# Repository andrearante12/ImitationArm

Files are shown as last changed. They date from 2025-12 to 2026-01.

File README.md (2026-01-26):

# ImitationArm
This document presents Imitation Arm, a 6DOF robotic arm that learns skills by watching human demonstrations and mimicing movements. The end goal is to create a generalized system where a human can record a video of them picking up and placing an object and upload that to the arm. The arm will then decode the video and be able to copy the exact motion the human made completely autonomously.

## System Overview
A human can train the robot via a wearable device consisting of an ESP32 microcontroller and a MPU-6050 Acceleromter and Gyroscope sensor. Data is streamed over WiFi to the central RaspberryPi using MQTT messaging protocol. The RaspberryPI is responsible for callibration and smoothing the sensor data using various signal processing techniques.

The robotic system is controlled by six MG996R pulse-width modulation (PWM) servomotors, which are driven by a PCA9685 16-channel, 12-bit PWM servo controller interfaced via the I2C protocol. Low-level actuator control is handled by an Arduino Nano microcontroller.

High-level system control is implemented on a Raspberry Pi running the Robot Operating System (ROS), which is responsible for computationally intensive control tasks. The ROS2 workspace can be download here: https://github.com/andrearante12/ros2_ws. A custom inverse kinematic algorithm implemented via gradient descent and used to convert target coordinates (x, y, z) into the corresponding servo angles. MoveIt2 was then used to create a motion plan and verify that the path is valid via trajectory planning and collision detection. Control commands are transmitted from the Raspberry Pi to the Arduino Nano over a serial communication interface.

## Future Direction

The following features are in development:
- Vision assisted callibration for wearable controller using D435 Depth Camera
- Reinforcement Learning Based (Imitation Learning) algorithm for autonomous task execution

## System Requirements
- Developed on Ubuntu 24.04 (required for ROS2 Jazzy)
- ROS2 - Jazzy 
- Moveit2 - Harmonic

## Physical Build and Demonstration

Demo Video using breadboard based protoype of wearable controller.

https://github.com/user-attachments/assets/144eaac5-5938-4217-9122-2242566a99c5

Rough prototype of wearable controller

https://github.com/user-attachments/assets/a6dace8c-65ac-41af-8a9c-40d3fd4ca57d

<p align="center">
  
  
</p>

## Visualization and motion planning with rviz2

https://github.com/user-attachments/assets/5d312841-a5a9-4a7e-a08d-b234987b8f20

Succesful motion planning demonstration

https://github.com/user-attachments/assets/f96ab1f5-55c6-4020-97d4-8c81f729513d

## Components
PCA9685 Servo Driver: https://www.amazon.com/dp/B0CNVBWX2M?ref=ppx_yo2ov_dt_b_fed_asin_title

Aluminum Body (w/out servos): https://www.amazon.com/dp/B01LW0LUPT?ref=ppx_yo2ov_dt_b_fed_asin_title

MG996R Digital Servo Motor (x6): https://www.amazon.com/dp/B09LS7RB5J?ref=ppx_yo2ov_dt_b_fed_asin_title&th=1

External Power Source (5V 6A): https://www.amazon.com/dp/B01D8FM4N4?ref=ppx_yo2ov_dt_b_fed_asin_title&th=1 





## CAD Model with Solidworks

Note: the above mentioned aluminum body doesn't come with an official CAD model, so the below and attached Solidworks file are my own personal recreation.

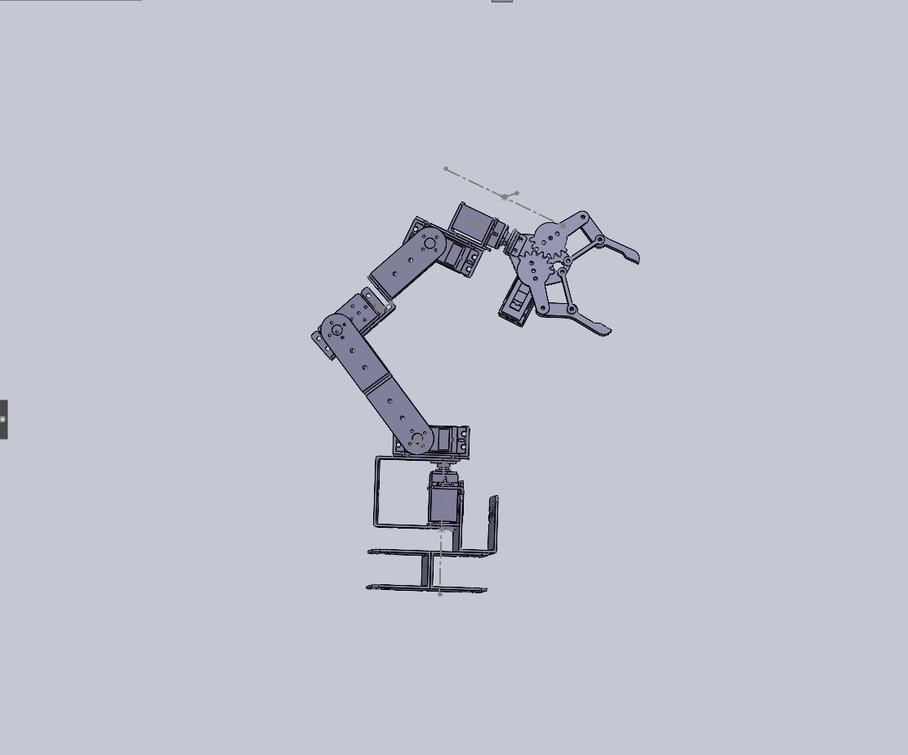
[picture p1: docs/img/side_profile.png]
Demo


### Steps to run

1. Install the ros2 package from this github repo: https://github.com/andrearante12/ros2_ws
```
cd ~/
git clone https://github.com/andrearante12/ros2_ws
```

2. Build the package (Full Rebuild)
```
cd ~/ros2_ws
rm -rf build install log
colcon build
source /opt/ros/jazzy/setup.bash
source install/setup.bash
```

Alternatively, a quick rebuild for select packages
```
cd ~/ros2_ws
colcon build --packages-select package_name
source install/setup.bash
```

3. Confirm that the distrubiton is working properly by launching the joint state manager with manual controls
```
ros2 launch robotic_arm robotic_arm.launch.py
```

## Starting the IMU Controller Pipeline

1. Run the motion planner with MoveIt and rviz2
```
ros2 launch robotic_arm_v3_config demo_with_controllers.launch.py
```

2. Run the IMU communication node
```
ros2 run mqtt_imu mqtt_imu_node
```

3. Run the IMU controller node

Run with the recommended callibration 
```
ros2 run esp32_controller esp32_controller --ros-args \
  -p callback_skip_rate:=5 \
  -p x_sensitivity:=3.0 \
  -p lock_y_axis:=true \
  -p default_y_position:=-1.2 \
  -p lock_wrist:=true \
  -p default_wrist_angle:=90 \
  -p default_z_position:=1.10

```

# ESP32 Controller - Quick Parameter Reference

| Parameter | Type | Default | Range/Options | Description |
|---|---|---|---|---|
| `callback_skip_rate` | int | 5 | 1-100 | Commands sent every N callbacks (higher = slower) |
| `x_sensitivity` | double | 1.5 | 0.1-10.0 | X-axis responsiveness (higher = more sensitive) |
| `y_sensitivity` | double | 2.0 | 0.1-10.0 | Y-axis responsiveness (higher = more sensitive) |
| `lock_x_axis` | bool | false | true/false | Lock X at current position |
| `lock_y_axis` | bool | false | true/false | Lock Y at default position |
| `lock_wrist` | bool | false | true/false | Lock wrist at default angle |
| `wrist_sensitivity` | double | 1.0 | 0.1-5.0 | Wrist rotation responsiveness |
| `default_y_position` | double | -1.35 | -1.5 to -1.2 | Y position when locked (meters) |
| `default_wrist_angle` | int | 90 | 0-180 | Wrist angle when locked (degrees) |
| `default_z_position` | double | 1.11 | 0.5-2.0 | Fixed Z height (meters) |

## Quick Examples
```bash
# Default (all features enabled)
ros2 run esp32_controller esp32_controller

# X-axis only (Y and wrist locked)
ros2 run esp32_controller esp32_controller --ros-args \
  -p lock_y_axis:=true \
  -p lock_wrist:=true

# High sensitivity, fast updates
ros2 run esp32_controller esp32_controller --ros-args \
  -p callback_skip_rate:=2 \
  -p x_sensitivity:=3.0 \
  -p y_sensitivity:=3.0

# Safe/slow for testing
ros2 run esp32_controller esp32_controller --ros-args \
  -p callback_skip_rate:=10 \
  -p x_sensitivity:=0.5 \
  -p y_sensitivity:=0.5
```

## Workspace Bounds
- **X:** 0.6 to 0.77 meters
- **Y:** -1.5 to -1.2 meters  
- **Z:** Fixed at `default_z_position`

## Starting the Inverse Kinematics Pipeline

1. Run the motion planner with MoveIt and rviz2
```
ros2 launch robotic_arm_v3_config demo_with_controllers.launch.py
```

2. Run pose_printer node to connect the device drivers to the simulation output
```
ros2 run pose_printer pose_printer
```

3. Send a plan (x, y, z) target coordinates with the move_program node
```
ros2 run move_program move_program 0.7 -1.2 1.145
```

5. Manual spawn robot model into gazebo for physics simulation (Optional, and buggy)
```
gz service -s /world/empty/create   --reqtype gz.msgs.EntityFactory   --reptype gz.msgs.Boolean   --req "sdf_filename: 'model://robotic_arm_model_v3', name: 'robotic_arm'"
```

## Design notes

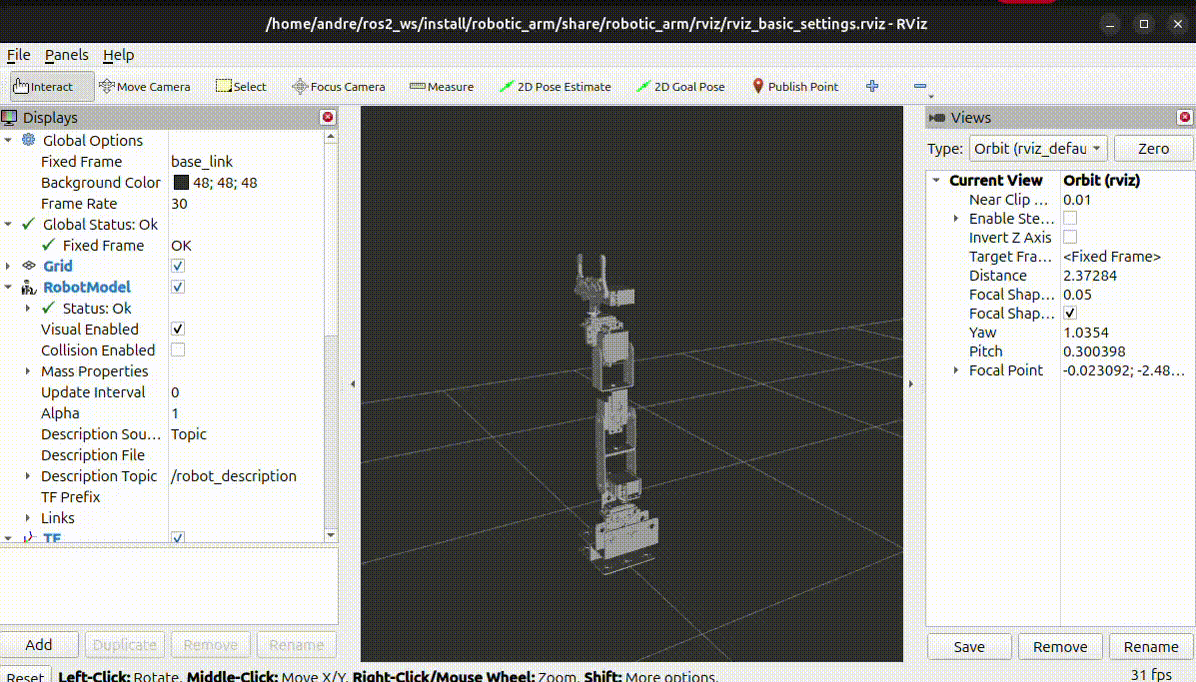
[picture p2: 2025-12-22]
docs/videos/rviz2_demo.gif

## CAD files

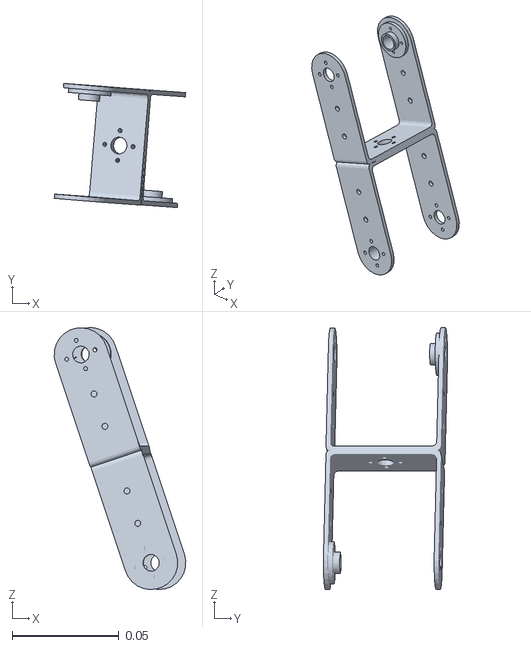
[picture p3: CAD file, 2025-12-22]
robotic_arm_model/robotic_arm_model_v2/meshes/Link_3.STL
0.0616 x 0.0582 x 0.123

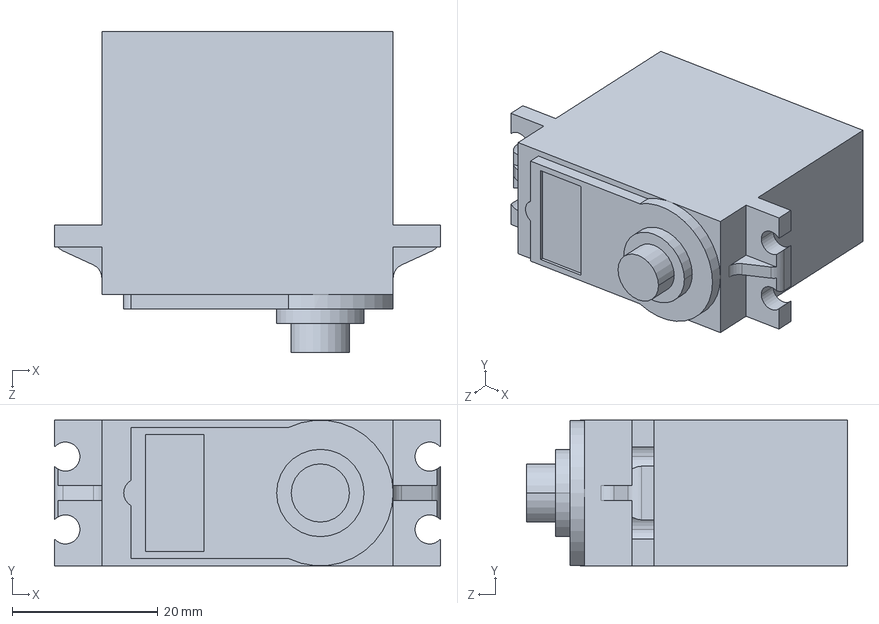
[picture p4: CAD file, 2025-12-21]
robotic_arm_model/final/simplified_servo.SLDPRT
53.0 x 20.0 x 44.1 mm

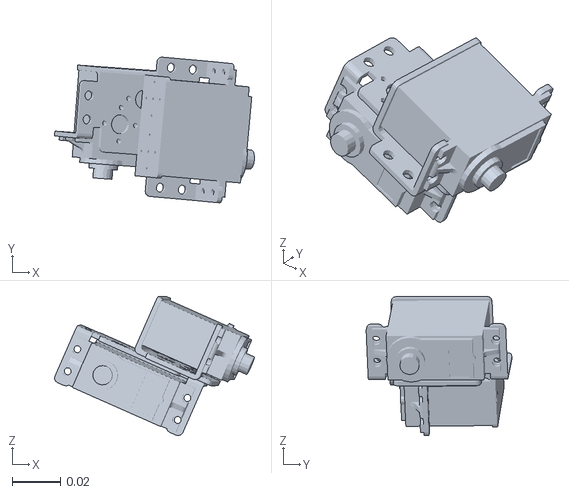
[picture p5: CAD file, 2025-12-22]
robotic_arm_model/robotic_arm_model_v2/meshes/Link_5.STL
0.0829 x 0.0605 x 0.0577

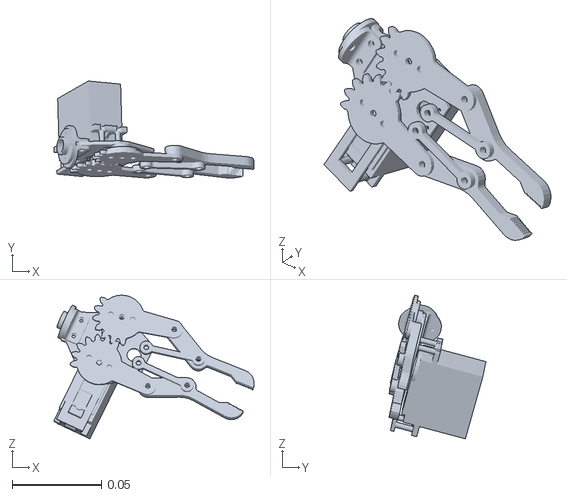
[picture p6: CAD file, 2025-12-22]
robotic_arm_model/robotic_arm_model_v2/meshes/Link_6.STL
0.112 x 0.0543 x 0.0804

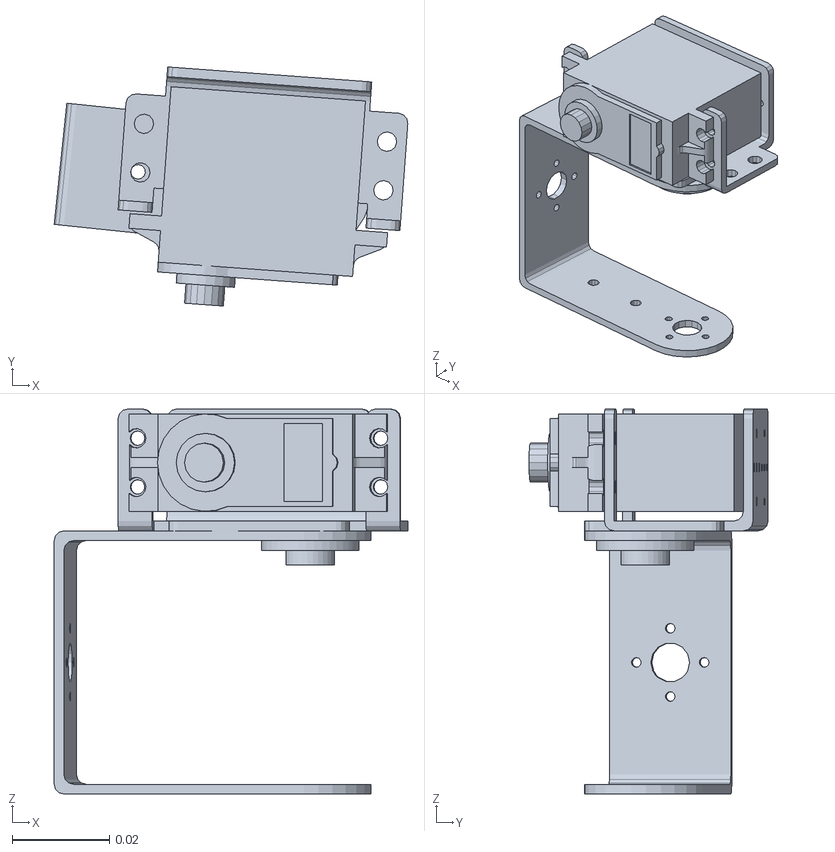
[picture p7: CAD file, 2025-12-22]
robotic_arm_model/robotic_arm_model_v2/meshes/Link_2.STL
0.0726 x 0.0491 x 0.079

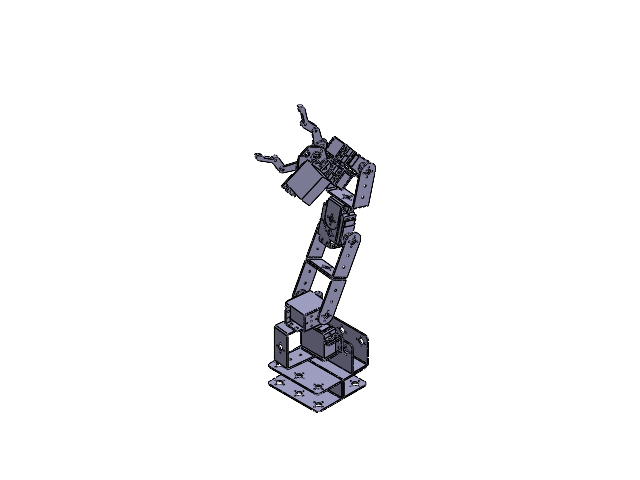
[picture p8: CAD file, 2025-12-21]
robotic_arm_model/final/final_model.SLDASM
base_bracket x 3
servo_holder x 5
u_shaped_arm_bracket x 4
servo_bearing x 7
Servomoteur_MG995.catpart
simplified_servo x 5
l_shaped_hinge
end_effector_attachment x 2
end_effector_base
end_effector_gear x 2
end_effector_claw x 2

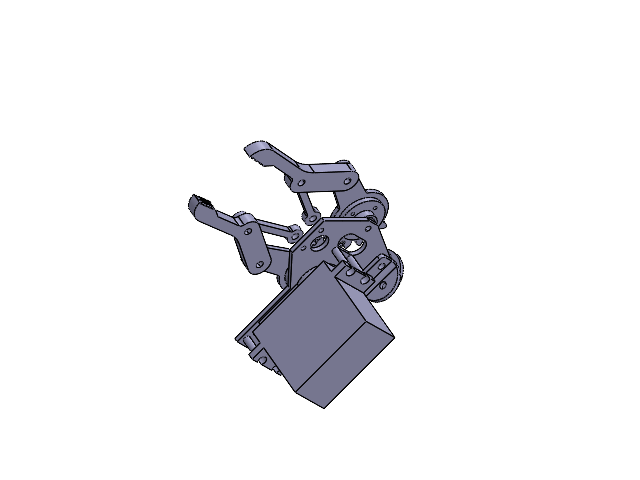
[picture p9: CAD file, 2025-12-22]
robotic_arm_model/final/links/link6.SLDASM
end_effector_claw x 2
end_effector_gear x 2
servo_bearing x 3
simplified_servo
end_effector_base
end_effector_attachment x 2
end_effector_support_beam x 2

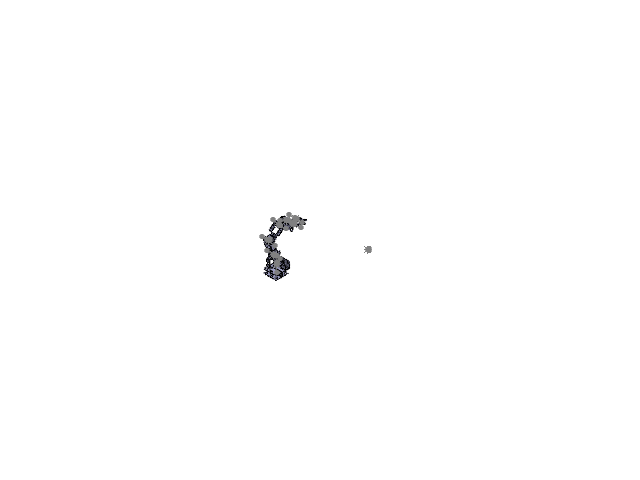
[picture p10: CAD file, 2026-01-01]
robotic_arm_model/robotic_arm_model_v3.SLDASM
base_bracket x 3
servo_holder x 5
simplified_servo x 6
servo_bearing x 6
u_shaped_arm_bracket x 4
l_shaped_hinge
end_effector_base
end_effector_attachment x 2
end_effector_claw x 2
end_effector_gear x 2

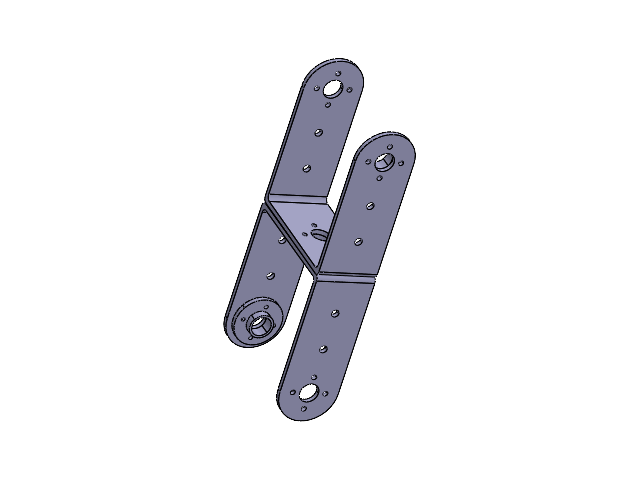
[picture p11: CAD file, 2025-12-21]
robotic_arm_model/final/links/link3.SLDASM
servo_bearing x 2
u_shaped_arm_bracket x 2

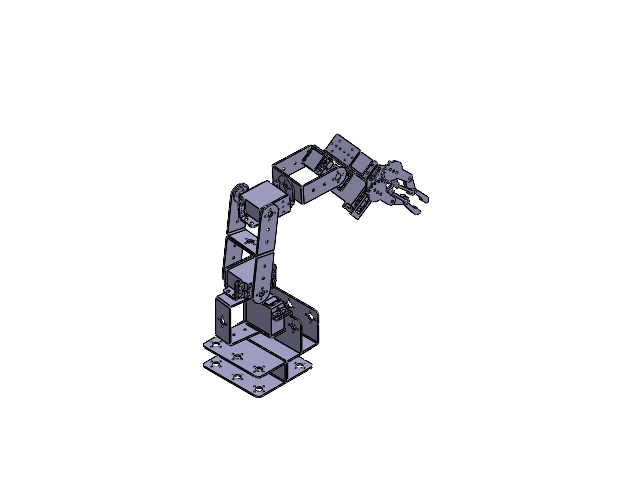
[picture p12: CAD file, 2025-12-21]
robotic_arm_model/final/final_model _urdf.SLDASM
base_bracket x 3
servo_holder x 5
simplified_servo x 6
servo_bearing x 6
u_shaped_arm_bracket x 4
l_shaped_hinge
end_effector_base
end_effector_attachment x 2
end_effector_claw x 2
end_effector_gear x 2
end_effector_support_beam x 2

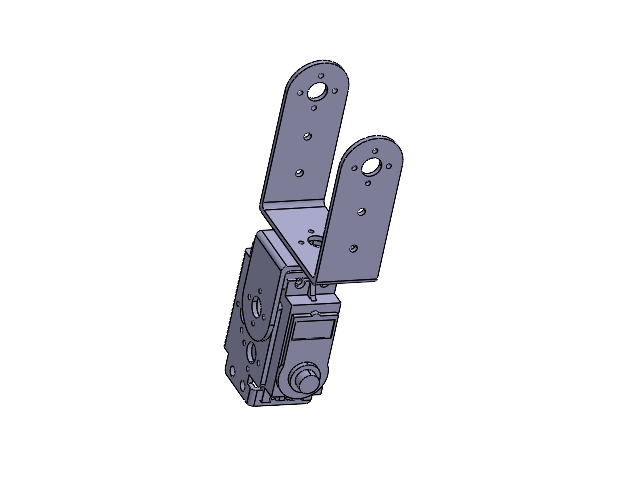
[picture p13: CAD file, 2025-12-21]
robotic_arm_model/final/links/link4.SLDASM
u_shaped_arm_bracket
l_shaped_hinge
servo_holder
simplified_servo

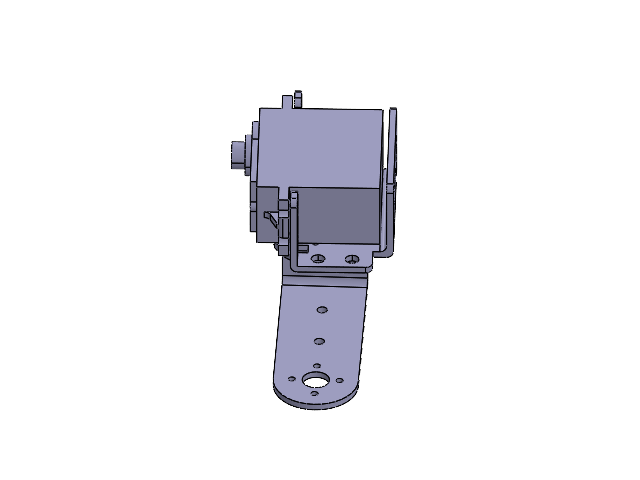
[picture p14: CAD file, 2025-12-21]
robotic_arm_model/final/link2.SLDASM
servo_bearing
u_shaped_arm_bracket
simplified_servo
servo_holder

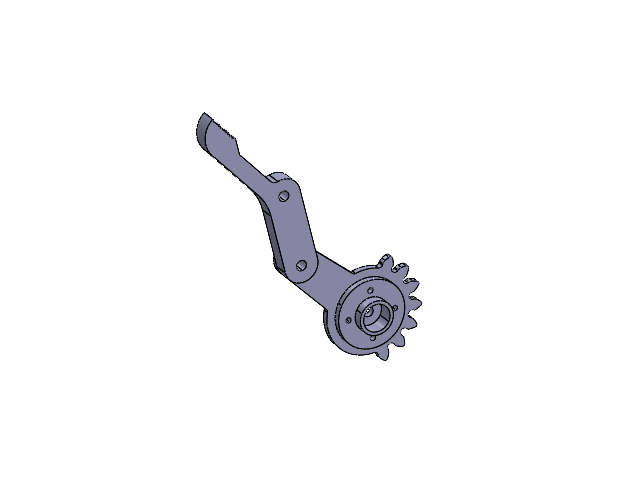
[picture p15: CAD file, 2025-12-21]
robotic_arm_model/final/links/link8.SLDASM
end_effector_claw
end_effector_gear
servo_bearing

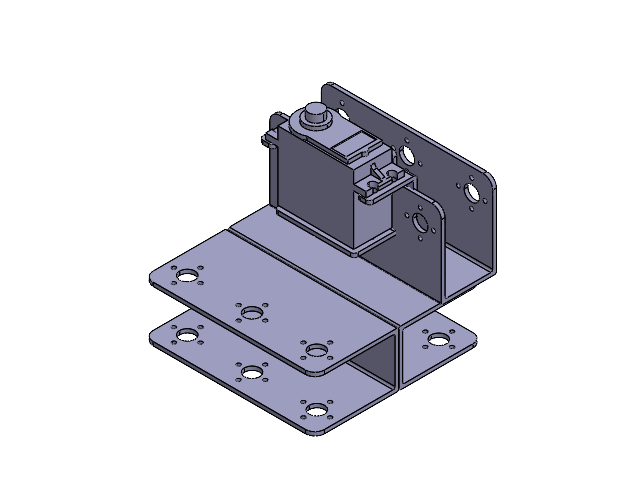
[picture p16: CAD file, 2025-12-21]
robotic_arm_model/final/links/link1.SLDASM
base_bracket x 3
servo_holder
simplified_servo

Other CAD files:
robotic_arm_model/final/links/link9.SLDASM
robotic_arm_model/final/links/link7.SLDASM
robotic_arm_model/final/links/link5.SLDASM
robotic_arm_model/final/links/link10.SLDASM
robotic_arm_model/final/base_bracket.SLDPRT
robotic_arm_model/final/end_effector_attachment.SLDPRT
robotic_arm_model/final/end_effector_base.SLDPRT
robotic_arm_model/final/end_effector_claw.SLDPRT
robotic_arm_model/final/end_effector_gear.SLDPRT
robotic_arm_model/final/end_effector_support_beam.SLDPRT
robotic_arm_model/final/final_model _urdf - Copy.SLDASM
robotic_arm_model/final/l_shaped_hinge.SLDPRT
robotic_arm_model/final/servo_bearing.SLDPRT
robotic_arm_model/final/servo_holder.SLDPRT
robotic_arm_model/final/u_shaped_arm_bracket.SLDPRT
robotic_arm_model/robotic_arm_model.SLDASM
robotic_arm_model/robotic_arm_model/full_assembly.SLDASM
robotic_arm_model/robotic_arm_model/l_shape_hook.SLDPRT
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

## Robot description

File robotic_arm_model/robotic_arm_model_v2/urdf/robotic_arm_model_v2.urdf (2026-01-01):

<?xml version="1.0" encoding="utf-8"?>
<!-- This URDF was automatically created by SolidWorks to URDF Exporter! Originally created by Stephen Brawner (brawner@gmail.com) 
     Commit Version: 1.6.0-4-g7f85cfe  Build Version: 1.6.7995.38578
     For more information, please see http://wiki.ros.org/sw_urdf_exporter -->
<robot name="robotic_arm_model_v2">
  <link name="Link_1">
    <inertial>
      <origin xyz="0.00139306780894399 -0.00940529906912735 0.0453587398679983" rpy="0 0 0" />
      <mass value="0.0953444546366154" />
      <inertia ixx="5.93899507525618E-05" ixy="-1.95760719485949E-08" ixz="-1.60400346152967E-07" iyy="2.6536038073633E-05" iyz="-1.32399943739737E-07" izz="5.70826120419313E-05" />
    </inertial>
    <visual>
      <origin xyz="0 0 0" rpy="0 0 0" />
      <geometry>
        <mesh filename="package://robotic_arm_model_v2/meshes/Link_1.STL" />
      </geometry>
      <material name="">
        <color rgba="0.752941176470588 0.752941176470588 0.752941176470588 1" />
      </material>
    </visual>
    <collision>
      <origin xyz="0 0 0" rpy="0 0 0" />
      <geometry>
        <mesh filename="package://robotic_arm_model_v2/meshes/Link_1.STL" />
      </geometry>
    </collision>
  </link>
  <link name="Link_2">
    <inertial>
      <origin xyz="-0.00834673768181382 0.0592848892623844 -0.0104318358374922" rpy="0 0 0" />
      <mass value="0.0465317343045151" />
      <inertia ixx="1.28967179873652E-05" ixy="-1.15476212501747E-07" ixz="-2.00612047421851E-06" iyy="1.41046479531017E-05" iyz="1.1020913809783E-07" izz="1.28042688740714E-05" />
    </inertial>
    <visual>
      <origin xyz="0 0 0" rpy="0 0 0" />
      <geometry>
        <mesh filename="package://robotic_arm_model_v2/meshes/Link_2.STL" />
      </geometry>
      <material name="">
        <color rgba="0.752941176470588 0.752941176470588 0.752941176470588 1" />
      </material>
    </visual>
    <collision>
      <origin xyz="0 0 0" rpy="0 0 0" />
      <geometry>
        <mesh filename="package://robotic_arm_model_v2/meshes/Link_2.STL" />
      </geometry>
    </collision>
  </link>
  <joint name="Joint_1" type="continuous">
    <origin xyz="0 0 0.05" rpy="0 0 0" />
    <parent link="Link_1" />
    <child link="Link_2" />
    <axis xyz="0 1 0" />
  </joint>
  <link name="Link_3">
    <inertial>
      <origin xyz="-0.00411555735719238 -0.0490782066853519 0.0151869177885213" rpy="0 0 0" />
      <mass value="0.0196331437668371" />
      <inertia ixx="8.60828290211513E-06" ixy="-6.25849778733872E-07" ixz="-2.65465712392E-06" iyy="1.03763652187604E-05" iyz="1.48452113073735E-06" izz="1.38316237538039E-05" />
    </inertial>
    <visual>
      <origin xyz="0 0 0" rpy="0 0 0" />
      <geometry>
        <mesh filename="package://robotic_arm_model_v2/meshes/Link_3.STL" />
      </geometry>
      <material name="">
        <color rgba="0.752941176470588 0.752941176470588 0.752941176470588 1" />
      </material>
    </visual>
    <collision>
      <origin xyz="0 0 0" rpy="0 0 0" />
      <geometry>
        <mesh filename="package://robotic_arm_model_v2/meshes/Link_3.STL" />
      </geometry>
    </collision>
  </link>
  <joint name="Joint_2" type="continuous">
    <origin xyz="-0.013808 0.068 -0.014468" rpy="0 0 0" />
    <parent link="Link_2" />
    <child link="Link_3" />
    <axis xyz="1 0 0" />
  </joint>
  <link name="Link_4">
    <inertial>
      <origin xyz="-0.00444665491595025 0.0223202695441305 -0.00518263328273361" rpy="0 0 0" />
      <mass value="0.0527193093497026" />
      <inertia ixx="1.35233138733539E-05" ixy="-6.51337467875423E-07" ixz="-2.45290637972249E-06" iyy="1.23208076947286E-05" iyz="1.80348552476092E-06" izz="1.78382591990529E-05" />
    </inertial>
    <visual>
      <origin xyz="0 0 0" rpy="0 0 0" />
      <geometry>
        <mesh filename="package://robotic_arm_model_v2/meshes/Link_4.STL" />
      </geometry>
      <material name="">
        <color rgba="0.752941176470588 0.752941176470588 0.752941176470588 1" />
      </material>
    </visual>
    <collision>
      <origin xyz="0 0 0" rpy="0 0 0" />
      <geometry>
        <mesh filename="package://robotic_arm_model_v2/meshes/Link_4.STL" />
      </geometry>
    </collision>
  </link>
  <joint name="Joint_3" type="continuous">
    <origin xyz="-0.011907 -0.098173 0.028798" rpy="0 0 0" />
    <parent link="Link_3" />
    <child link="Link_4" />
    <axis xyz="1 0 0" />
  </joint>
  <link name="Link_5">
    <inertial>
      <origin xyz="0.000679680189040077 0.0122665484013129 0.0211158228704872" rpy="0 0 0" />
      <mass value="0.0734303247872166" />
      <inertia ixx="1.38233645740671E-05" ixy="8.61051491118209E-07" ixz="-2.17371805074157E-06" iyy="1.39325618071774E-05" iyz="-2.30776403389571E-06" izz="1.90390713191208E-05" />
    </inertial>
    <visual>
      <origin xyz="0 0 0" rpy="0 0 0" />
      <geometry>
        <mesh filename="package://robotic_arm_model_v2/meshes/Link_5.STL" />
      </geometry>
      <material name="">
        <color rgba="0.752941176470588 0.752941176470588 0.752941176470588 1" />
      </material>
    </visual>
    <collision>
      <origin xyz="0 0 0" rpy="0 0 0" />
      <geometry>
        <mesh filename="package://robotic_arm_model_v2/meshes/Link_5.STL" />
      </geometry>
    </collision>
  </link>
  <joint name="Joint_4" type="continuous">
    <origin xyz="0.0087856 0.094286 -0.021316" rpy="0 0 0" />
    <parent link="Link_4" />
    <child link="Link_5" />
    <axis xyz="1 0 0" />
  </joint>
  <link name="Link_6">
    <inertial>
      <origin xyz="0.000490956447003033 0.0365600823816492 0.0629614150153786" rpy="0 0 0" />
      <mass value="0.0505964512602664" />
      <inertia ixx="9.1057804910603E-06" ixy="-4.1013347615792E-07" ixz="3.07553808060529E-07" iyy="8.4892606377326E-06" iyz="1.22622100929367E-06" izz="8.6626497442181E-06" />
    </inertial>
    <visual>
      <origin xyz="0 0 0" rpy="0 0 0" />
      <geometry>
        <mesh filename="package://robotic_arm_model_v2/meshes/Link_6.STL" />
      </geometry>
      <material name="">
        <color rgba="0.752941176470588 0.752941176470588 0.752941176470588 1" />
      </material>
    </visual>
    <collision>
      <origin xyz="0 0 0" rpy="0 0 0" />
      <geometry>
        <mesh filename="package://robotic_arm_model_v2/meshes/Link_6.STL" />
      </geometry>
    </collision>
  </link>
  <joint name="Joint_5" type="continuous">
    <origin xyz="0.0075284 0.0019156 0.035067" rpy="0 0 0" />
    <parent link="Link_5" />
    <child link="Link_6" />
    <axis xyz="0 -1 -1" />
  </joint>
</robot>

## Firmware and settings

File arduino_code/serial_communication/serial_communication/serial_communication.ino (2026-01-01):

#include <Adafruit_PWMServoDriver.h>

Adafruit_PWMServoDriver board1 = Adafruit_PWMServoDriver(0x40);

#define SERVOMIN 125  // Minimum pulse length (0 degrees)
#define SERVOMAX 625  // Maximum pulse length (180 degrees)



void setup() {
// Serial communication initialization
  Serial.begin(9600);
  
  board1.begin();
  board1.setPWMFreq(60); // Servos operate at ~60 Hz

  // Reset servo to default position
  reset();
  
}


void loop() {  
  
  if (Serial.available()) {
    String input = Serial.readStringUntil('\n');
    int servo, angle;
  
    if (parseServoCommand(input, servo, angle)) {
      

      // Fix Joint_1 (servo0) 0 --> 130
      if (servo == 0) {
        angle += 100;  
        angle = clamp(angle, 40, 160);
      }

      // Fix Joint_2 (servo1) 0 --> 90
      if (servo == 1) {

        angle -= 45;
        angle *= -1;
//        // Clamp angle to [55, 175]
//        angle = clamp(angle, -85, 35);
        
      }

      if (servo == 2) {
        angle *= -1;  
      }

      if (servo == 3) {
        angle *= -1;
        angle += 45;
      }

      board1.setPWM(servo, 0, angleToPulse(angle));
    
      Serial.print("Servo ");
      Serial.print(servo);
      Serial.print(" set to ");
      Serial.print(angle);
      Serial.println("°");
    } else {
      Serial.println("Invalid command. Format: servo3=45");
    }

  }
  
}

int clamp(int angle, int min_val, int max_val) {
  if (angle < min_val) {
      angle = min_val;
  } 
  else if (angle > max_val) {
      angle = max_val;
  }
  return angle;

  
}

void reset() {
//  board1.setPWM(0, 0, angleToPulse(0)); // Servo 0 (Base)
//  board1.setPWM(1, 0, angleToPulse(0)); // Servo 1 (Bottom Arm)
//  board1.setPWM(2, 0, angleToPulse(0)); // Servo 2 (Mid Arm)
//  board1.setPWM(3, 0, angleToPulse(0)); // Servo 3 (Wrist)
  board1.setPWM(4, 0, angleToPulse(0)); // Servo 4 (Hand Rotation)
  board1.setPWM(5, 0, angleToPulse(45)); // Servo 5 (Grip) Range for grip is 45-90 degrees without overstraining servo
}

int angleToPulse(int ang) {
  int pulse = map(ang, 0, 180, SERVOMIN, SERVOMAX);
  return pulse;
}


bool parseServoCommand(String cmd, int &servo, int &angle) {
  cmd.trim();

  // Must start with "servo"
  if (!cmd.startsWith("servo")) return false;

  // Must contain '='
  int eqIndex = cmd.indexOf('=');
  if (eqIndex == -1) return false;

  // Extract parts
  String servoStr = cmd.substring(5, eqIndex);
  String angleStr = cmd.substring(eqIndex + 1);

  // Servo must be digits only (no negative servos)
  for (char c : servoStr) {
    if (!isDigit(c)) return false;
  }

  // Angle may be negative
  int start = 0;
  if (angleStr.startsWith("-")) {
    if (angleStr.length() == 1) return false; // "-" only is invalid
    start = 1;
  }

  for (int i = start; i < angleStr.length(); i++) {
    if (!isDigit(angleStr[i])) return false;
  }

  servo = servoStr.toInt();
  angle = angleStr.toInt();

  return true;
}

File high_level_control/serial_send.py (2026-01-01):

import serial
import sys
import time

# Serial Port and Speed Settings
serial_port = '/dev/ttyUSB1'  # Check if ACM0 instead!
baud_rate = 9600

# Serial Port Initialization
ser = serial.Serial(serial_port, baud_rate, timeout=1)
time.sleep(2)  # Allow Arduino to reset

def send_data(data):
    ser.write((data + "\n").encode())  # Always send newline
    ser.flush()

    # Listen for Arduino response
    time.sleep(0.05)  # Give it time to respond
    while ser.in_waiting > 0:
        response = ser.readline().decode().strip()
        if response:
            print("Arduino:", response)

if __name__ == "__main__":
    if len(sys.argv) != 2:
        print("Usage: python send_data.py servo3=45")
        sys.exit(1)

    command = sys.argv[1]
    send_data(command)
    print("Sent:", command)

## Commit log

2025-12-22 enabled visualization with rviz2
    [base_link.STL, end_effector.STL, link_1.STL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]
2025-12-22 Clean commit after reset
    [Link_1.STL, Link_2.STL, Link_3.STL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]
2026-01-01 cleaned up file structure
    [Link_1.STL, Link_2.STL, Link_3.STL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]
